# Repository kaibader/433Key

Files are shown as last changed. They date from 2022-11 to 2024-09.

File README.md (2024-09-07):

# LoRa Breakout Board for RFM95/RFM96 and SX1276/SX1278 Modules

This repository contains KiCad design files for a breadboard-friendly breakout board that supports various LoRa modules, such as the **HopeRF RFM95/RFM96** or Semtech **SX1276/SX1278**-based modules like the HPD13A and G-NiceRF LoRa1276-C1.

## Features

| Top View | Bottom View |
| --- | --- |
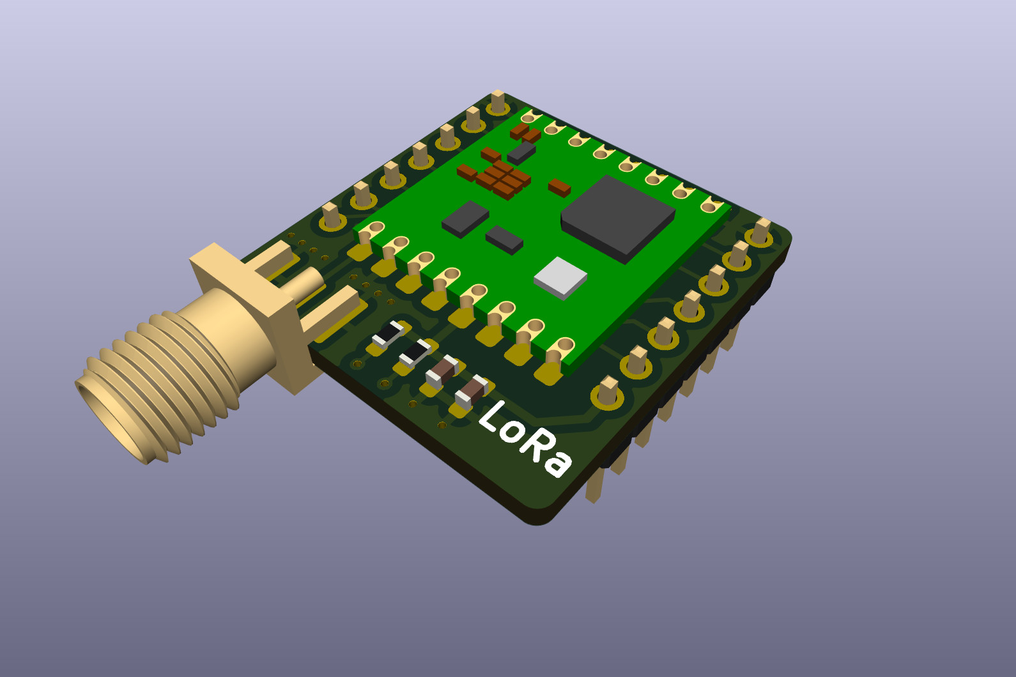
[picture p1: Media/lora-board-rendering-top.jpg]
Top View
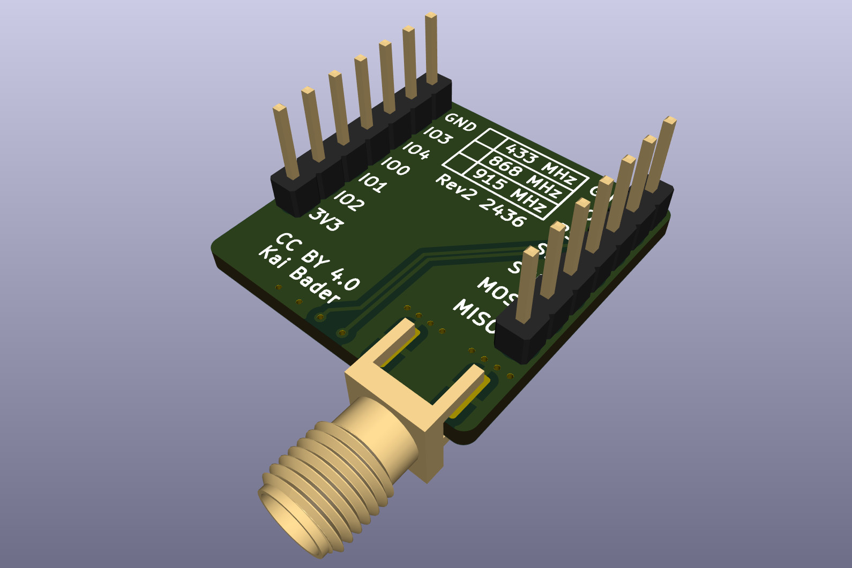
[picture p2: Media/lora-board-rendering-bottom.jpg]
Bottom View info
|  |  |

- Supports **HopeRF RFM95/RFM96** and other pin-compatible LoRa modules.
- Designed to fit standard breadboards for easy prototyping.
- Simple SPI-based communication with microcontrollers.

## Schematic Overview

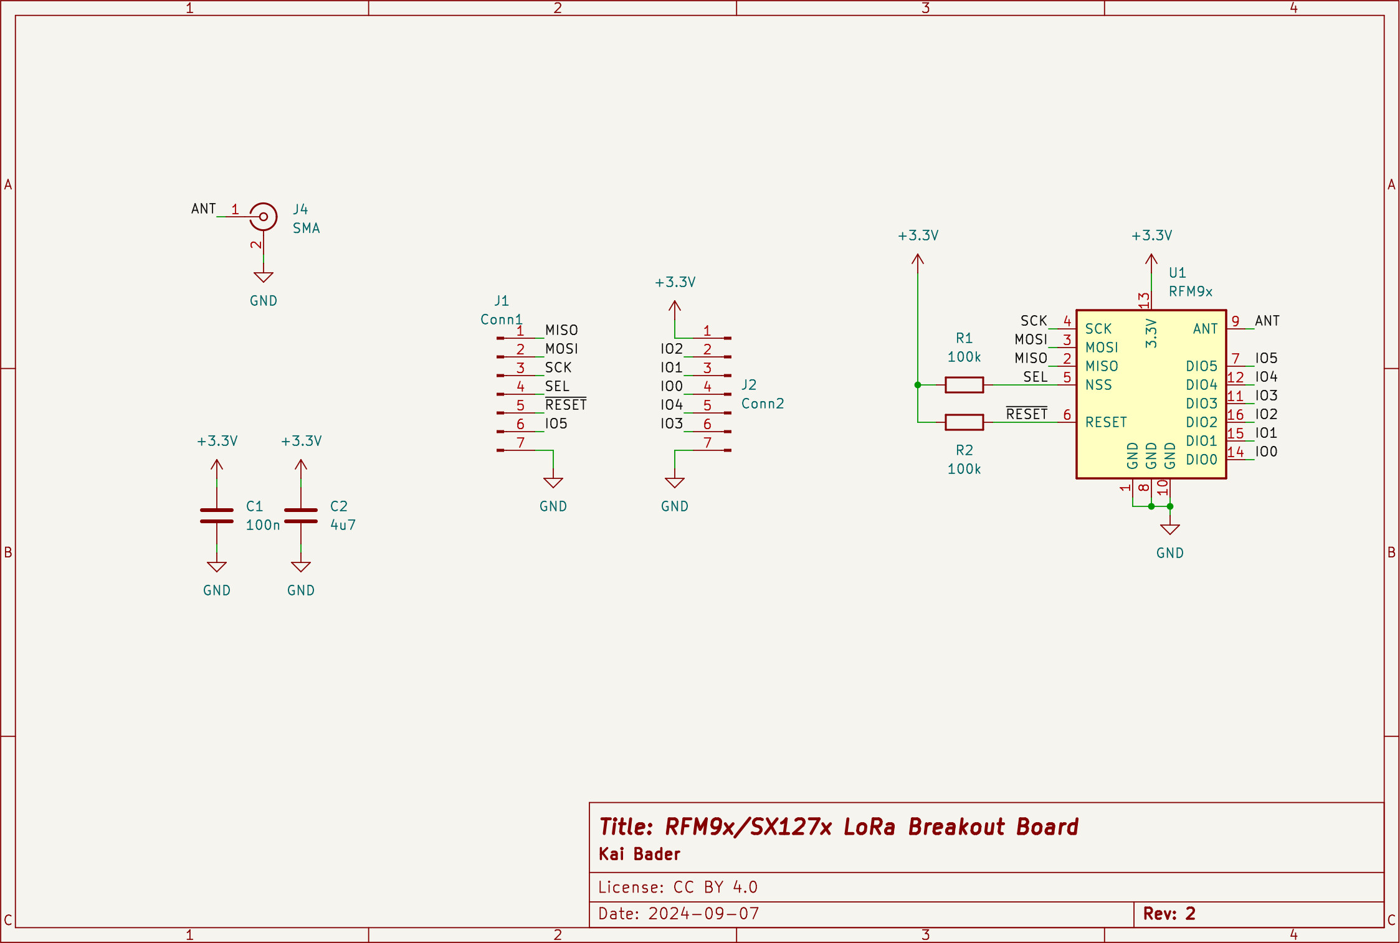
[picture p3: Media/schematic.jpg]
Schematic


The breakout board includes the following key components and connections:

### 1. **LoRa Module**
   - This module, based on the SX1276 transceiver, handles LoRa communication at 868 MHz or 915 MHz.
   - It communicates with the microcontroller via the **SPI interface** (SCK, MOSI, MISO, NSS pins).
   - Additional **DIO pins (DIO0-DIO5)** are exposed, allowing the module to send interrupts or general-purpose I/O signals.
   - **Antenna**: The RFM9x is connected to an external antenna via an SMA connector for wireless communication.

### 2. **SPI Interface**
   - The SPI interface is used to connect the RFM9x to a microcontroller, with signals for **MISO, MOSI, SCK, NSS (SEL)**, and a **RESET** pin.
   - This enables the module to send and receive data through standard SPI communication.

### 3. **DIO Pin Connector**
   - The board provides access to the **DIO0-DIO5 pins**, which are general-purpose input/output pins for signaling and interrupt control. These can be connected to a microcontroller for event-driven handling of LoRa transmissions.

### 4. **Antenna Connection (SMA)**
   - The **SMA connector** is used to attach an external antenna, which is crucial for enabling long-range LoRa communication.

### 5. **Power Supply and Decoupling Capacitors**
   - The board operates at **+3.3V** and includes two decoupling capacitors:
     - **C1 (100nF)** and **C2 (4.7uF)** help filter out noise and stabilize the power supply to ensure proper operation of the LoRa module.
   - These capacitors prevent voltage fluctuations from affecting the module's performance, especially during transmission.

### 6. **Reset Circuit**
   - The **RESET pin** is connected to a 100k pull-up resistor **(R2)**, and another 100k resistor **(R1)** is used to control the accessibility (via **SEL**) of the module.
   - This allows external control for reinitializing the module as needed.

## Pin-Compatible LoRa Modules

This breakout board is designed to be compatible with the **HopeRF RFM9x** series and the following pin-compatible alternatives:

1. **HopeRF RFM95** (by HopeRF):
   - A widely used LoRa transceiver module that supports long-range, low-power wireless communication.
   - **Manufacturer**: [HopeRF](https://www.hoperf.com).

2. **HPD13A** (by HPD Technology):
   - A pin-compatible and shielded alternative to the RFM95, based on the SX1276 transceiver.
   - **Manufacturer**: [HPD Technology](http://www.hpdtek.com).

3. **G-NiceRF LoRa1276-C1** (by NiceRF):
   - A pin-compatible module using the same SX1276 chip as the HPD13A, designed for similar wireless communication applications.
   - **Manufacturer**: [NiceRF](https://www.nicerf.com).

Feel free to inform me about other alternatives that are available and pin-compatible.

## License

This project is licensed under the **Creative Commons Attribution 4.0 International (CC BY 4.0)**. See the [LICENSE](https://creativecommons.org/licenses/by/4.0/) page for details.

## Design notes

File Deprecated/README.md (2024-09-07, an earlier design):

# Deprecated Breakout Board Designs

This folder contains older breakout board designs for various RF modules that are no longer actively maintained or supported. These designs have been moved from the main repository to this subfolder for archival purposes. While they can still be used, please note that they may not meet modern standards or compatibility requirements.

For current and actively supported designs, please refer to the main repository [here](../README.md).

## Deprecated Modules

### 1. **RFM12**
   - **Frequency Bands**: 433 MHz, 868 MHz, 915 MHz.
   - **Features**: A popular low-power FSK transceiver module used for sub-GHz communication.
   - **Applications**: Suitable for wireless sensor networks, home automation, and low-power telemetry.

### 2. **RFM26W**
   - **Frequency Bands**: Sub-GHz frequencies.
   - **Features**: Long-range wireless communication with low power consumption.
   - **Applications**: Ideal for IoT applications and long-range sensor networks.

### 3. **RFM69W**
   - **Frequency Bands**: 315 MHz, 433 MHz, 868 MHz, 915 MHz.
   - **Features**: A versatile low-power transceiver module capable of FSK, GFSK, and OOK modulation.
   - **Applications**: Widely used for wireless networks, industrial control, and telemetry.

### 4. **RFM9xW**
   - **Frequency Bands**: 868 MHz, 915 MHz.
   - **Features**: LoRa-based long-range communication with enhanced penetration through obstacles.
   - **Applications**: Best suited for long-range wireless sensor networks, IoT applications, and remote monitoring.

## Important Notes

- **No Active Support**: These designs are no longer actively maintained or updated. Use at your own discretion, and note that modern alternatives with improved performance are available in the main repository.
- **Compatibility Issues**: These designs may not be compatible with newer systems or microcontrollers without modification. Users are encouraged to transition to more current designs if possible.

For the latest breakout boards supporting modern LoRa modules such as the RFM95/RFM96 series, please check the main project [here](../README.md).

## License

All designs in this folder remain licensed under the **Creative Commons Attribution 4.0 International (CC BY 4.0)**. You are free to use, share, and adapt these designs with appropriate credit. For more details, refer to the [LICENSE](https://creativecommons.org/licenses/by/4.0/).

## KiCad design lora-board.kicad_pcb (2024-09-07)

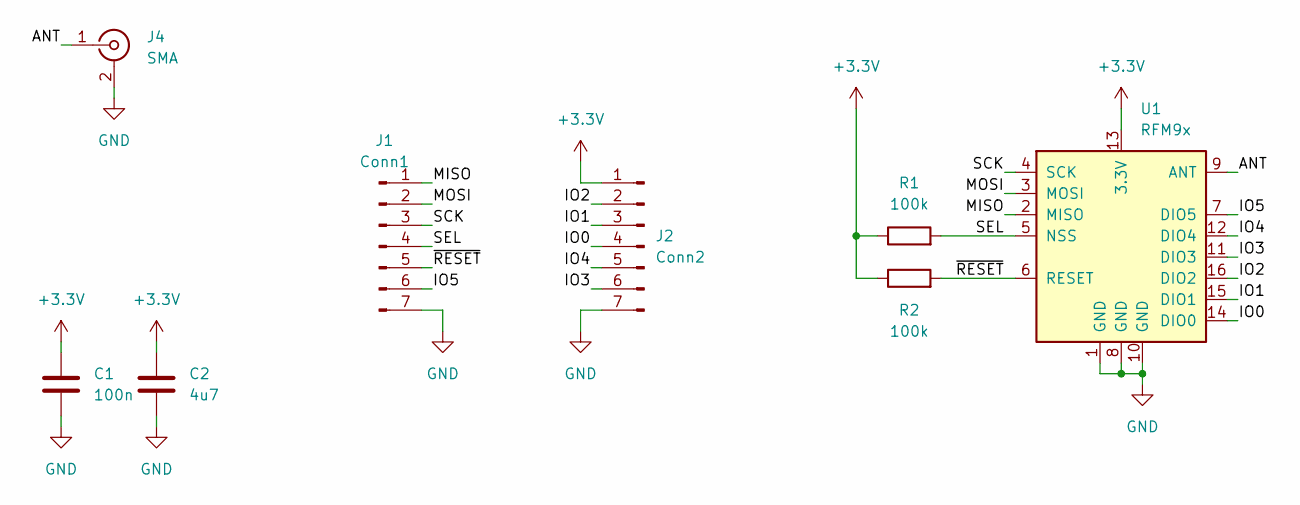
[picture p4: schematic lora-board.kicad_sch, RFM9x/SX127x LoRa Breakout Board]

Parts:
C1: 100n; C_0603_1608Metric_Pad1.08x0.95mm_HandSolder
C2: 4u7; C_0603_1608Metric_Pad1.08x0.95mm_HandSolder
J1: Conn1; PinHeader_1x07_P2.54mm_Vertical
J2: Conn2; PinHeader_1x07_P2.54mm_Vertical
J4: SMA; SMA_Samtec_SMA-J-P-H-ST-EM1_EdgeMount
R1, R2: 100k; R_0603_1608Metric_Pad0.98x0.95mm_HandSolder
U1: RFM9x; HOPERF_RFM9XW_SMD

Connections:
+3.3V: C1.1, C2.1, J2.1, R1.1, R2.1, U1.13 (3.3V)
/ANT: J4.1 (In), U1.9 (ANT)
/IO0: J2.4, U1.14 (DIO0)
/IO1: J2.3, U1.15 (DIO1)
/IO2: J2.2, U1.16 (DIO2)
/IO3: J2.6, U1.11 (DIO3)
/IO4: J2.5, U1.12 (DIO4)
/IO5: J1.6, U1.7 (DIO5)
/MISO: J1.1, U1.2 (MISO)
/MOSI: J1.2, U1.3 (MOSI)
/SCK: J1.3, U1.4 (SCK)
/SEL: J1.4, R1.2, U1.5 (NSS)
/~RESET: J1.5, R2.2, U1.6 (RESET)
GND: C1.2, C2.2, J1.7, J2.7, J4.2 (Ext), U1.1 (GND), U1.8 (GND), U1.10 (GND)

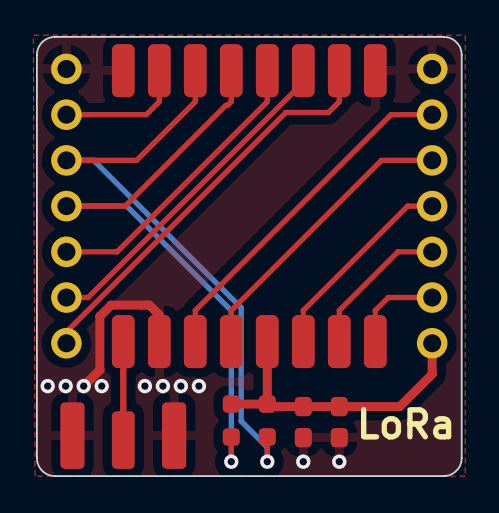
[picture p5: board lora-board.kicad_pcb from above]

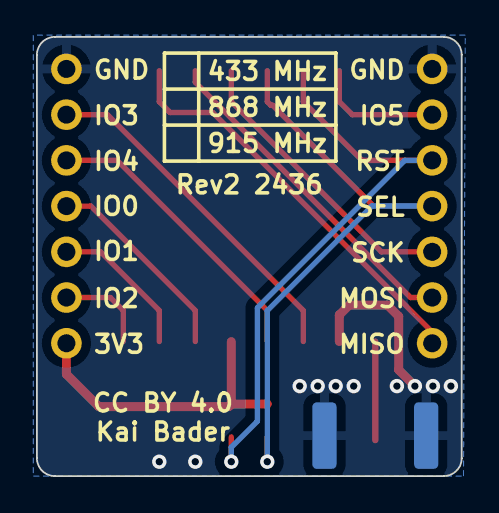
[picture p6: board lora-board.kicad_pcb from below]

Board: 2 copper layers, 23.6 x 24.4 mm, 8 parts (2 on the bottom side), 14 nets.

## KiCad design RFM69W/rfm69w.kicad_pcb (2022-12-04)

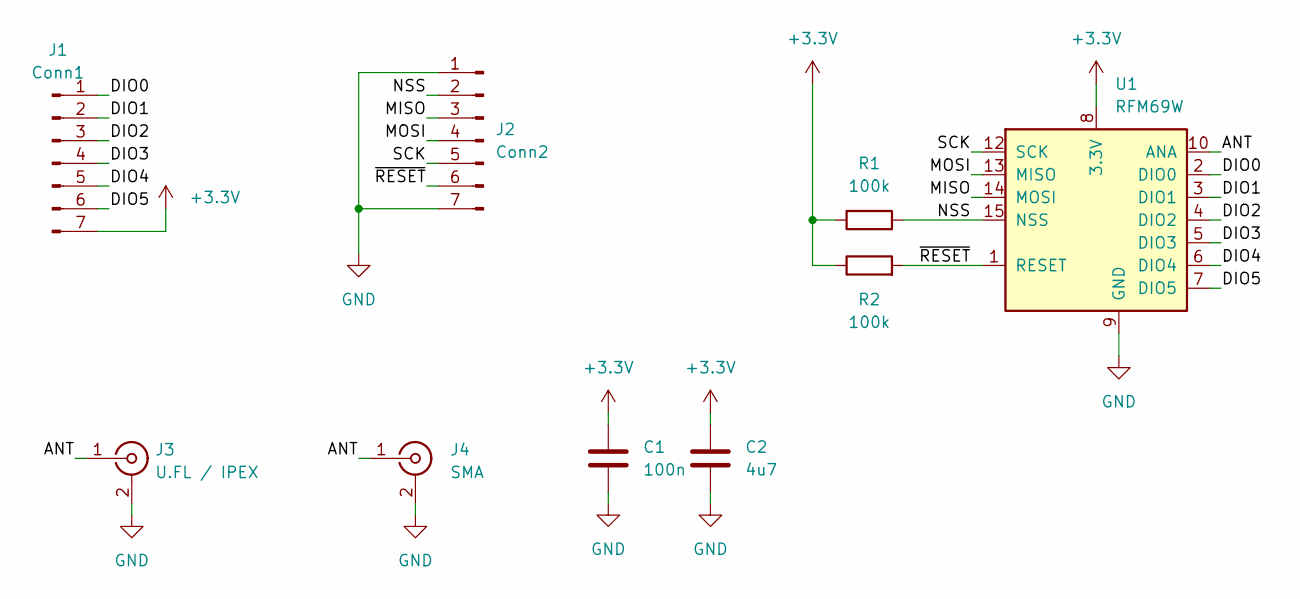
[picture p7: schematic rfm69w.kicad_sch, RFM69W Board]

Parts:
C1: 100n; C_0603_1608Metric_Pad1.08x0.95mm_HandSolder
C2: 4u7; C_0603_1608Metric_Pad1.08x0.95mm_HandSolder
J1: Conn1; PinHeader_1x07_P2.54mm_Vertical
J2: Conn2; PinHeader_1x07_P2.54mm_Vertical
J3: U.FL / IPEX; U.FL_Molex_MCRF_73412-0110_Vertical
J4: SMA; SMA_Samtec_SMA-J-P-X-ST-EM1_EdgeMount
R1, R2: 100k; R_0603_1608Metric_Pad0.98x0.95mm_HandSolder
U1: RFM69W; HOPERF_RFM69HW

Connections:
+3.3V: C1.1, C2.1, J1.7, R1.1, R2.1, U1.8 (3.3V)
/ANT: J3.1 (In), J4.1 (In), U1.10 (ANA)
/DIO0: J1.1, U1.2 (DIO0)
/DIO1: J1.2, U1.3 (DIO1)
/DIO2: J1.3, U1.4 (DIO2)
/DIO3: J1.4, U1.5 (DIO3)
/DIO4: J1.5, U1.6 (DIO4)
/DIO5: J1.6, U1.7 (DIO5)
/MISO: J2.3, U1.14 (MOSI)
/MOSI: J2.4, U1.13 (MISO)
/NSS: J2.2, R1.2, U1.15 (NSS)
/SCK: J2.5, U1.12 (SCK)
/~RESET: J2.6, R2.2, U1.1 (RESET)
GND: C1.2, C2.2, J2.1, J2.7, J3.2 (Ext), J4.2 (Ext), U1.9 (GND), U1.11 (GND)

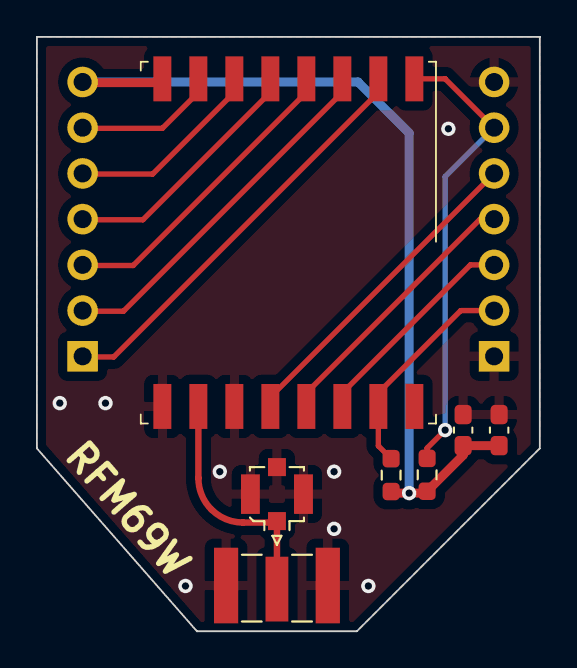
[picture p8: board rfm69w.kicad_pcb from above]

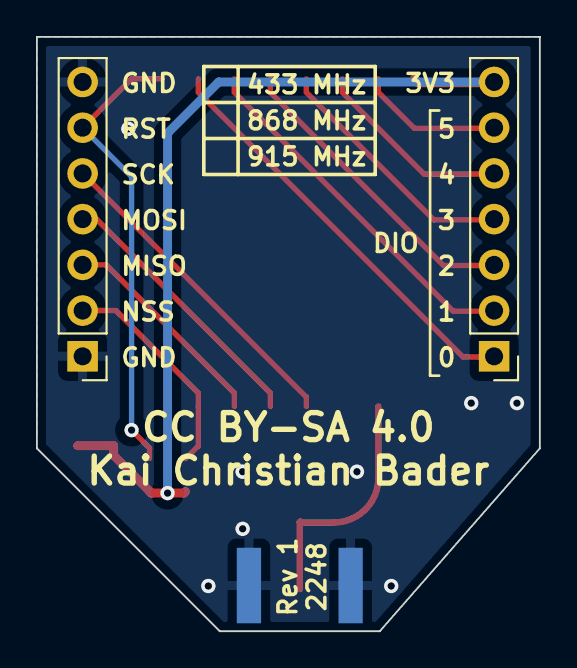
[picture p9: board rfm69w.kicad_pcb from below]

Board: 2 copper layers, 27.9 x 33.0 mm, 9 parts (2 on the bottom side), 14 nets.

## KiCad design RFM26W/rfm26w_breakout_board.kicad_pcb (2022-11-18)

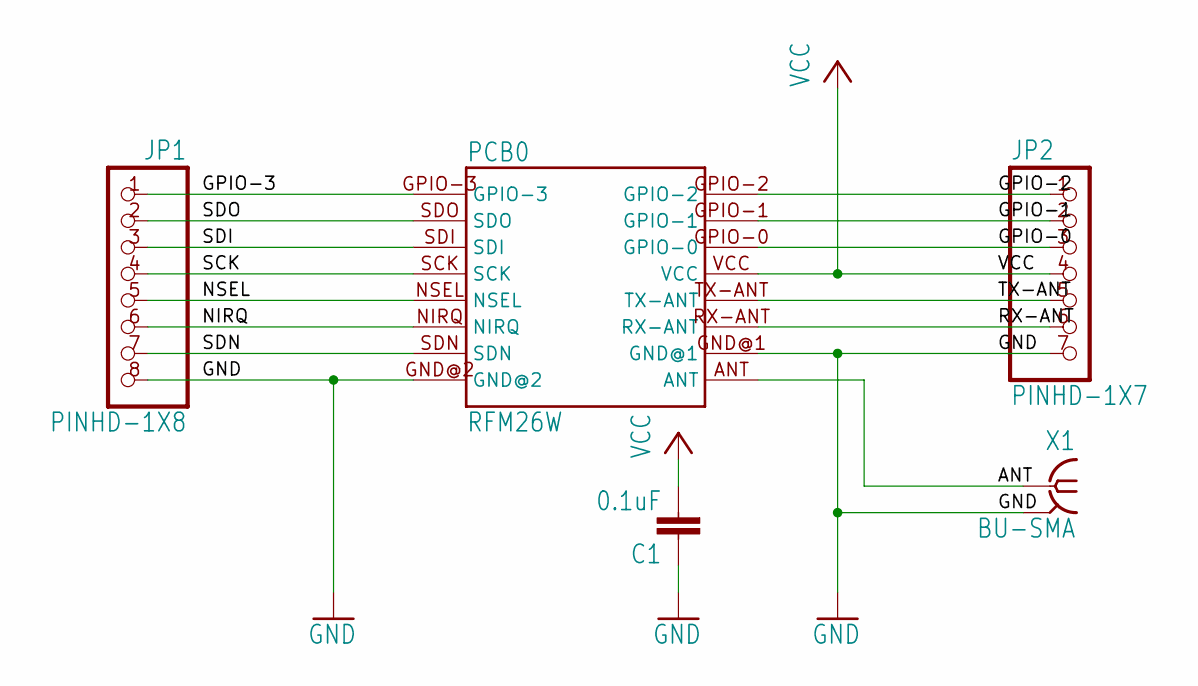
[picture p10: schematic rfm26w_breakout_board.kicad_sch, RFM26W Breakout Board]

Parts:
C1: 0.1uF; C0805K
JP1: PINHD-1X8; 1X08
JP2: PINHD-1X7; 1X07
PCB0: RFM26W
X1: BU-SMA; BU-SMA-V

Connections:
ANT: PCB0.ANT, X1.1
GND: C1.1, JP1.8, JP2.7, PCB0.GND@1, PCB0.GND@2, X1.2, X1.3 (2), X1.4 (2), X1.5 (2)
GPIO-0: JP2.3, PCB0.GPIO-0
GPIO-1: JP2.2, PCB0.GPIO-1
GPIO-2: JP2.1, PCB0.GPIO-2
GPIO-3: JP1.1, PCB0.GPIO-3
NIRQ: JP1.6, PCB0.NIRQ
NSEL: JP1.5, PCB0.NSEL
RX-ANT: JP2.6, PCB0.RX-ANT
SCK: JP1.4, PCB0.SCK
SDI: JP1.3, PCB0.SDI
SDN: JP1.7, PCB0.SDN
SDO: JP1.2, PCB0.SDO
TX-ANT: JP2.5, PCB0.TX-ANT
VCC: C1.2, JP2.4, PCB0.VCC

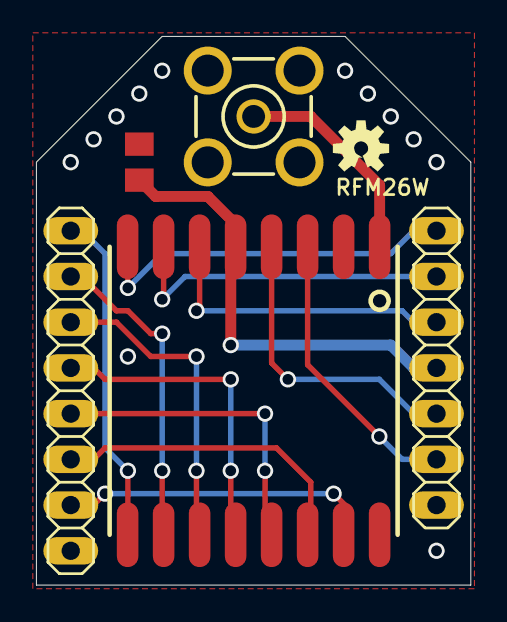
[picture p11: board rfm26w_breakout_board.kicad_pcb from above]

Board: 2 copper layers, 24.1 x 30.5 mm, 6 parts (0 on the bottom side), 15 nets.

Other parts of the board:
U$3: OSHW-LOGO-S

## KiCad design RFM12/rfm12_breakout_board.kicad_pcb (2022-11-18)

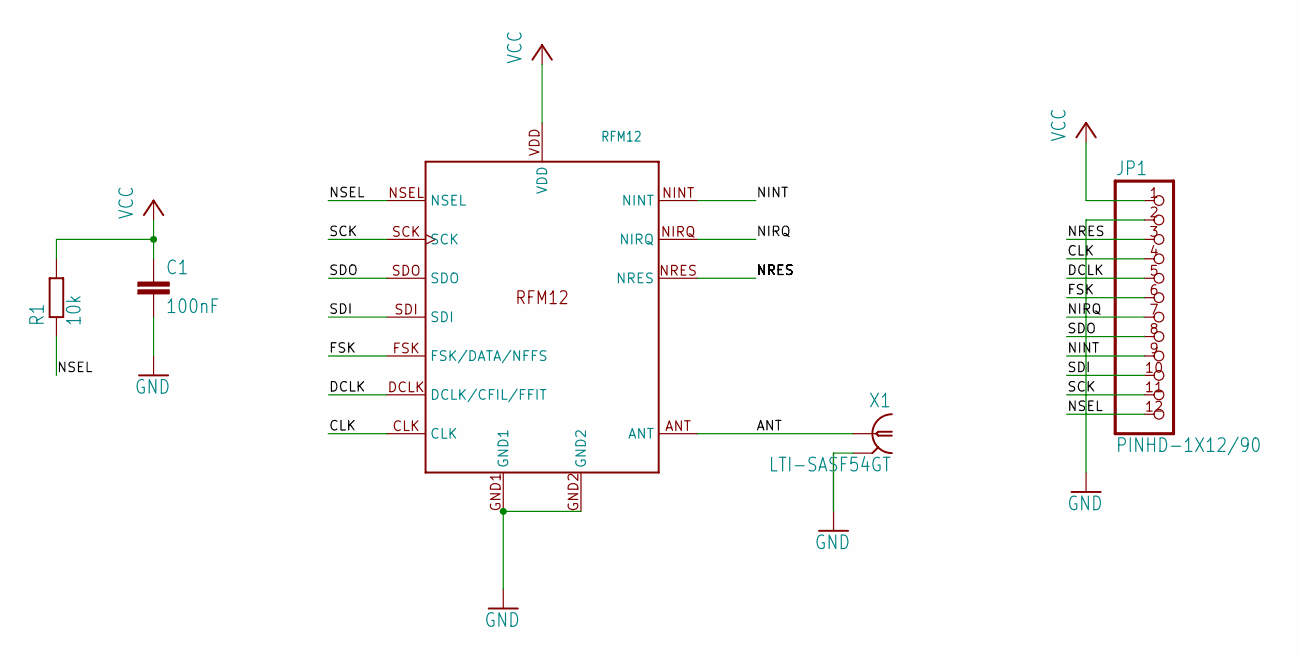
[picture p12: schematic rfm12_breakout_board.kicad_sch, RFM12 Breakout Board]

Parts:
C1: 100nF; C0805
JP1: PINHD-1X12/90; 1X12_90
R1: 10k; M0805
U$1: RFM12
X1: LTI-SASF54GT

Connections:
ANT: U$1.ANT, X1.1
CLK: JP1.4, U$1.CLK
DCLK: JP1.5, U$1.DCLK (DCLK/CFIL/FFIT)
FSK: JP1.6, U$1.FSK (FSK/DATA/NFFS)
GND: C1.2, JP1.2, U$1.GND1, U$1.GND2, X1.2, X1.3 (2), X1.4 (2), X1.5 (2)
NINT: JP1.9, U$1.NINT
NIRQ: JP1.7, U$1.NIRQ
NRES: JP1.3, U$1.NRES
NSEL: JP1.12, R1.1, U$1.NSEL
SCK: JP1.11, U$1.SCK
SDI: JP1.10, U$1.SDI
SDO: JP1.8, U$1.SDO
VCC: C1.1, JP1.1, R1.2, U$1.VDD

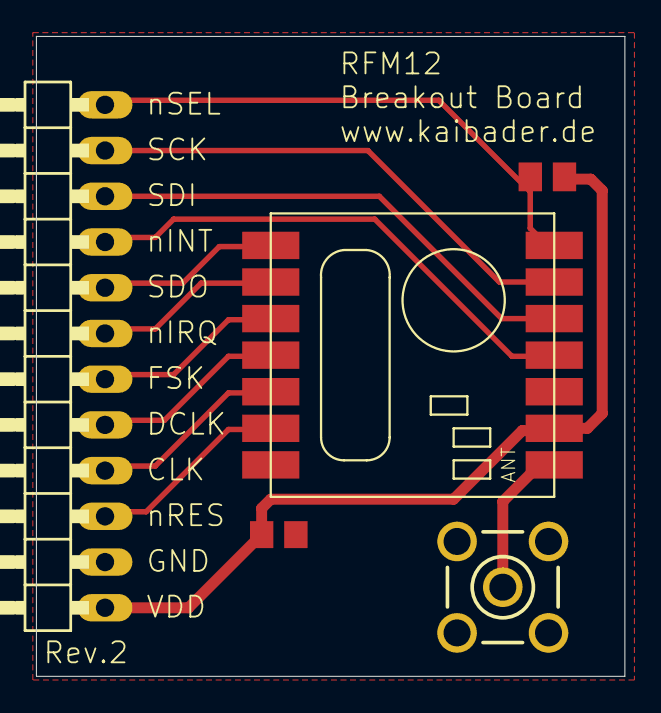
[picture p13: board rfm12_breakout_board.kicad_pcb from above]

Board: 2 copper layers, 32.7 x 35.5 mm, 5 parts (0 on the bottom side), 13 nets.

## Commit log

2015-10-11 Added files for the RFM12 Breakout Board.
    [rfm12_breakout_board.GBL, rfm12_breakout_board.GBO, rfm12_breakout_board.GBP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]
2015-10-11 Done some clean-up.
    [rfm12_breakout_board.GBL, rfm12_breakout_board.GBO, rfm12_breakout_board.GBP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]
2015-10-11 Added a RFM26W Breakout Board design.
    [rfm26w_breakout_board.brd, rfm26w_breakout_board.sch]
2015-10-11 Layout updates.
    [rfm26w_breakout_board.brd]
2015-10-11 Routed the RFM26W Breakout Board.
    [rfm26w_breakout_board.brd]
2015-10-11 Layout update
    [rfm26w_breakout_board.brd]
2015-10-11 Fixed the font line width to 6 mil.
    [rfm26w_breakout_board.brd]
2015-10-11 Added Gerber files.
    [rfm26w_breakout_board.GBL, rfm26w_breakout_board.GBO, rfm26w_breakout_board.GBP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]
2017-02-09 Switched the project frame to KiCad
    [433Key.kicad_pcb, 433Key.sch]
2017-02-09 Revert "Switched the project frame to KiCad"
    [433Key.kicad_pcb, 433Key.sch]
2022-11-18 Converted the RFM12 and RFM26W Breakout Board Projects from EagleCAD to KiCAD.
    [rfm12_breakout_board.GBL, rfm12_breakout_board.GBO, rfm12_breakout_board.GBP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]
2022-11-18 Added Specification PDFs
    [rfm26w_breakout_board.GBL, rfm26w_breakout_board.GBO, rfm26w_breakout_board.GBP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]
2022-11-27 Added RFM95/RFM96 and RFM69W Breakout Boards.
    [rfm69w.kicad_pcb, rfm69w.kicad_sch, rfm9x.kicad_pcb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]
2022-12-04 Updated the RFM69W and RFM95W/RFM96W board layouts.
    [rfm69w.kicad_pcb, rfm69w.kicad_sch, rfm9x.kicad_pcb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]
2022-12-04 Generated Gerber files.
    [rfm12_breakout_board.GBL, rfm12_breakout_board.GBO, rfm12_breakout_board.GBP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]
2024-09-07 LoRa Breakout Board Revision 2
    - Shifted the focus of the repository towards the new LoRa breakout board design.
    - Moved the old designs into a 'Deprecated' folder.
    - Added a ReadMe (Markdown).
    - Added module documentation.
    [lora-board-B_Cu.gbl, lora-board-B_Mask.gbs, lora-board-B_Paste.gbp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]

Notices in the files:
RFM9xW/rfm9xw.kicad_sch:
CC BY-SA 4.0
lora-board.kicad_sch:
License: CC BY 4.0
